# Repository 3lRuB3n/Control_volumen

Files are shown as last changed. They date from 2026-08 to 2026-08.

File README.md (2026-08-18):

# Instalación
## Requisitos
Circuitpython 
# Componentes y conexiones
A la hora de fabricar el hardware de este proyecto se han usado como base para las conexiones dos placas perforadas de 5x7cm.
## Componentes
- 1 Raspberry pi pico (Puede que funcione con una Raspberry pi pico 2)
- Módulo ESP01/ESP01s
- Pantalla oled 1.3in con controlado SH1106
- 5 Pulsadores del tipo (?) de 6x6x11.5 mm
- 1 Codificador rotativo del tipo EC11
- 1 Resistencia Pull-Up para el ESP01
## Conexiones
1. GP20, GP21: A, B codificador
2. GP6: Pulsador **Silenciar**
3. GP13: Pulsador **Siguiente** pista
4. GP15: Pulsador pista **Anterior**
5. GP14: Pulsador **Play/Pausa**
6. GP5: Pulsador **Cambio Dispositivo**
7. GP28: Pulsador **On/Off**

# Estructuras de los programas
## Estructura del programa de la Raspberry Pi
1. Code.py; Donde ocurre el bucle principal.
2. ControlDisplay.py; Encargado del control del SH1106.
3. Cadena2Imagen.py; Convierte un txt a bitmap de displayio
4. even.py; Encargado de declarar los inputs del dispositivo
5. recep.py; Alberga la clase **recep** y los métodos de envío a los dispositivos conectados por USB
6. wled.py; #TODO, capa de traducción de las funciones de esp.py para que las reconozca un dispositivo WLED
7. esp.py; Encargado de la comunicación con el módulo ESP01/01s, encargado de enviar comandos mediante ESPNow a otros receptores.
## Estructura del programa del ESP maestro
#TODO
## Estructura del programa del ESP esclavo
#TODO

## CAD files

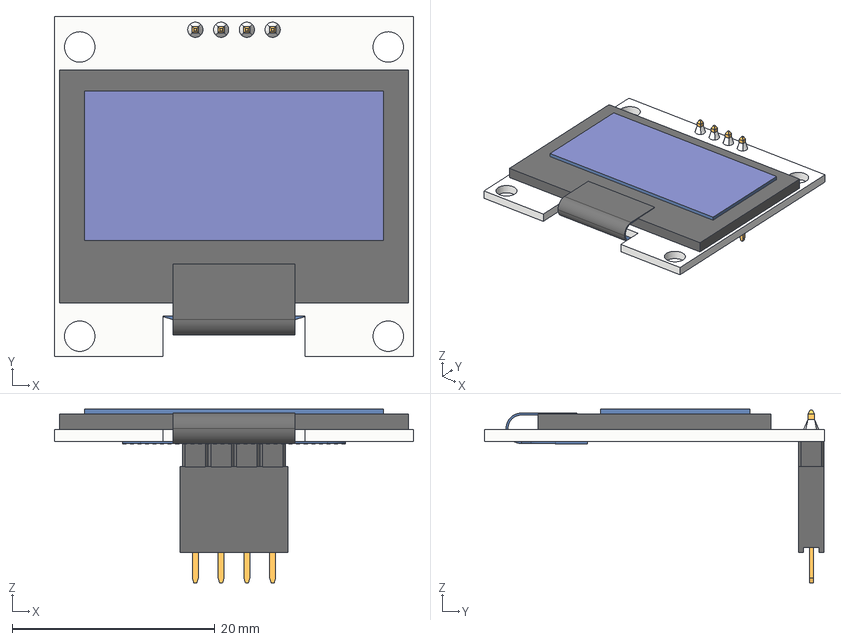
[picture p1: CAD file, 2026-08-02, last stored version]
CAD/128x64-1-3-inch-oled-graphic-display-4-pin-is-i2c-1.snapshot.3/PCB v8.step
35.4 x 33.5 x 17.1 mm
Board
PIN HEADER MALE 2.54MM P4
LCD
FLEX FILM
4 lü Lehim
PIN HEADER FAMALE 2.54MM P4

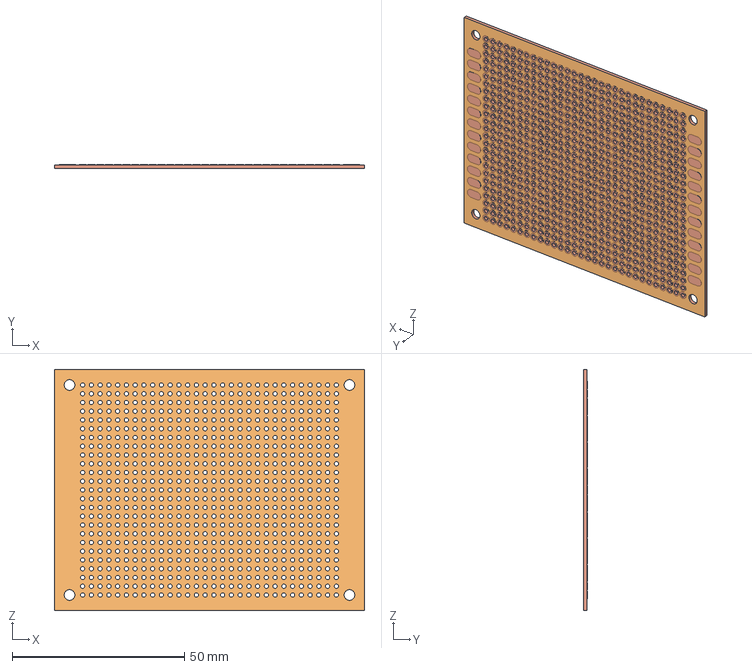
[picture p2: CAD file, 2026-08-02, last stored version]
CAD/adafruit-perfboard-1.snapshot.2/Adafruit_ProtoBoard.stp
90.0 x 1.05 x 70.0 mm

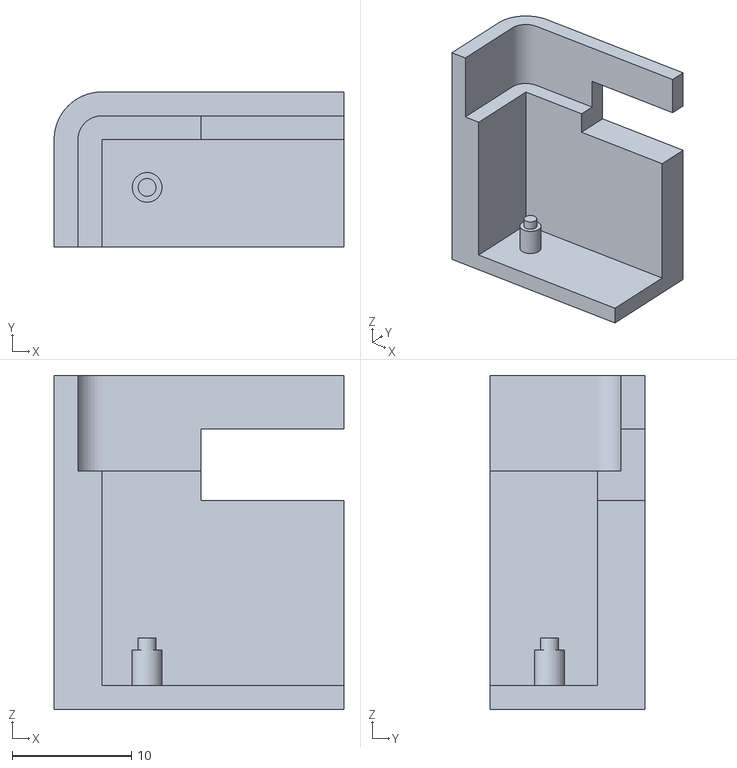
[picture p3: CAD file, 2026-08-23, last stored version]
CAD/Test base.stl
24.3 x 13.0 x 28.0

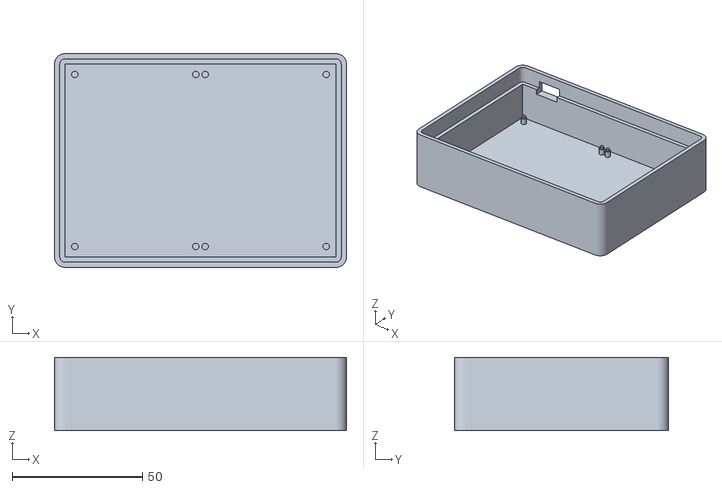
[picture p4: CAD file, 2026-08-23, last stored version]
CAD/Base.stl
112.0 x 82.0 x 28.0

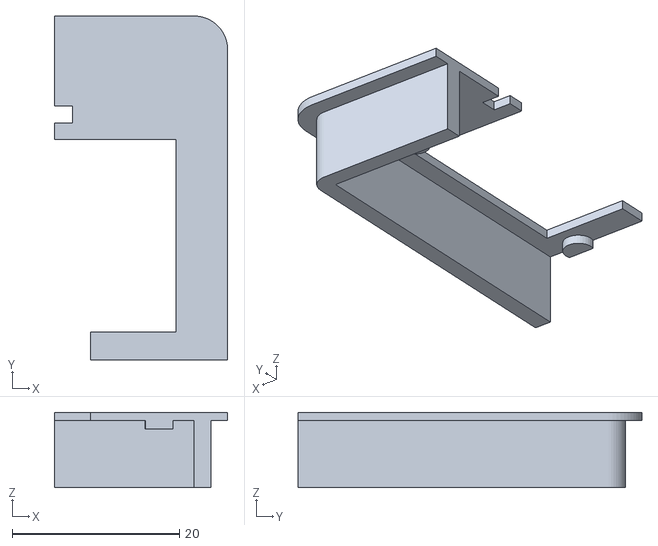
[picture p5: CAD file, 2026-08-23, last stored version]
CAD/Test Tapa.stl
20.7 x 41.1 x 9.00

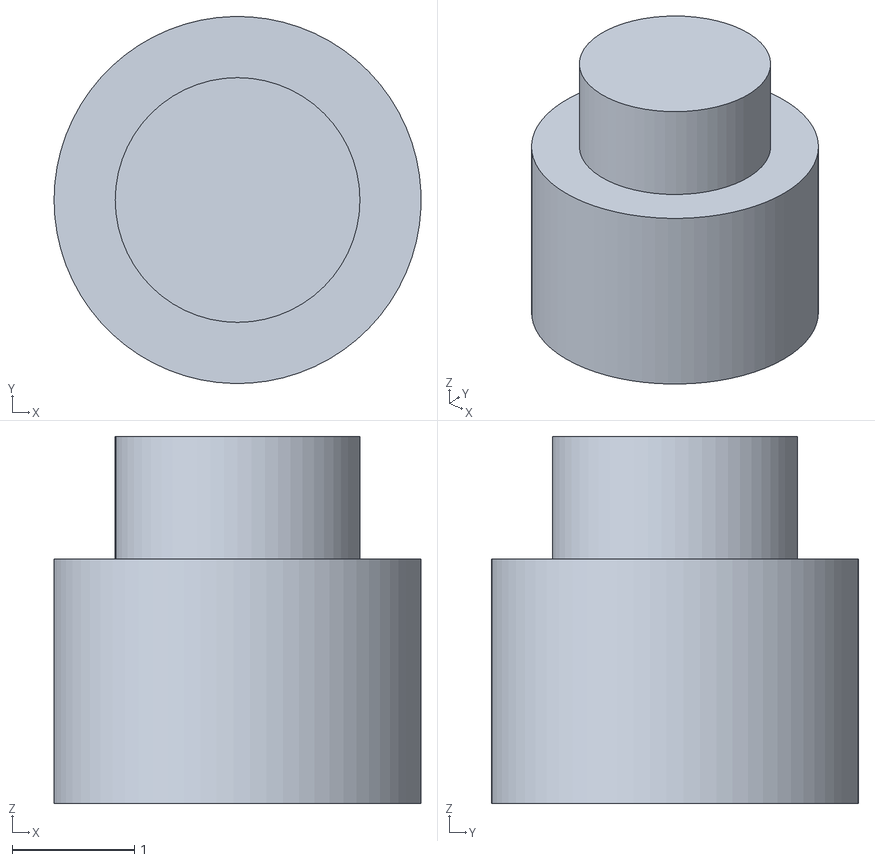
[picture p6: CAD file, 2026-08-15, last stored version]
CAD/Cono prueba.stl
3.00 x 3.00 x 3.00

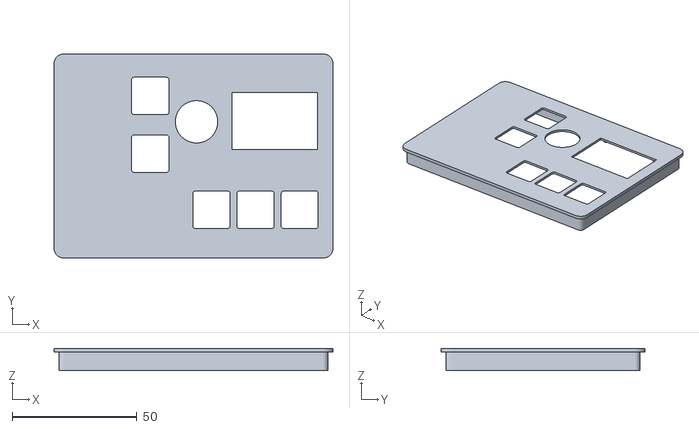
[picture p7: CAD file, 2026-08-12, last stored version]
CAD/Tapa.stl
112.0 x 82.0 x 9.00

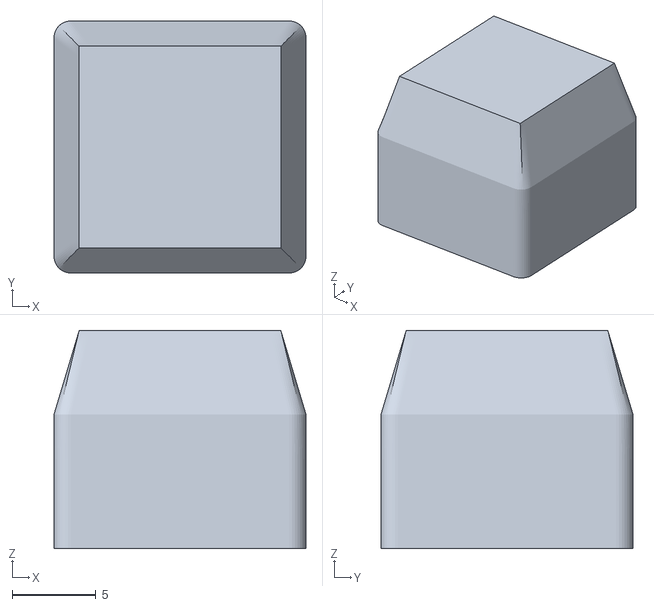
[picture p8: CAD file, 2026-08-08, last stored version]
CAD/Tecla.stl
15.0 x 15.0 x 13.0

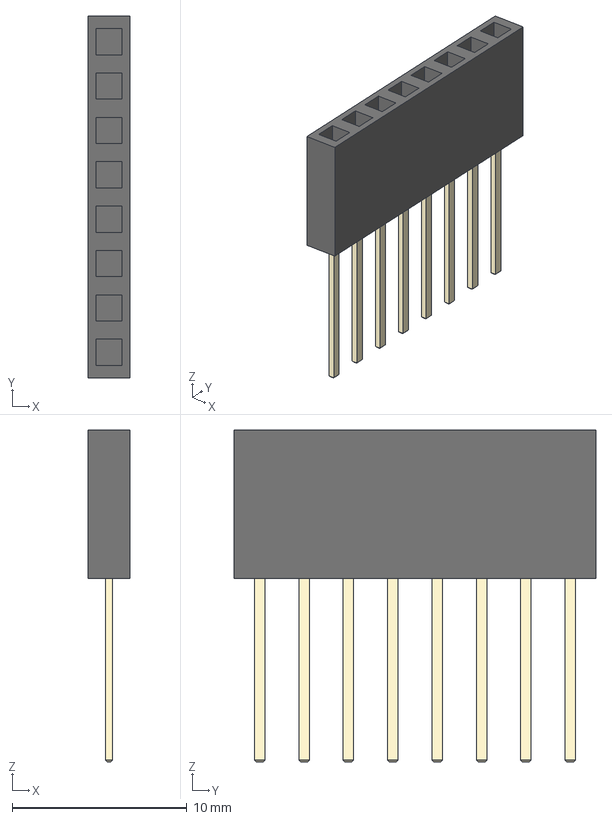
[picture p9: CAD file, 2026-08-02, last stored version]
CAD/Conectores pines hembra macho.step
2.40 x 20.7 x 19.0 mm

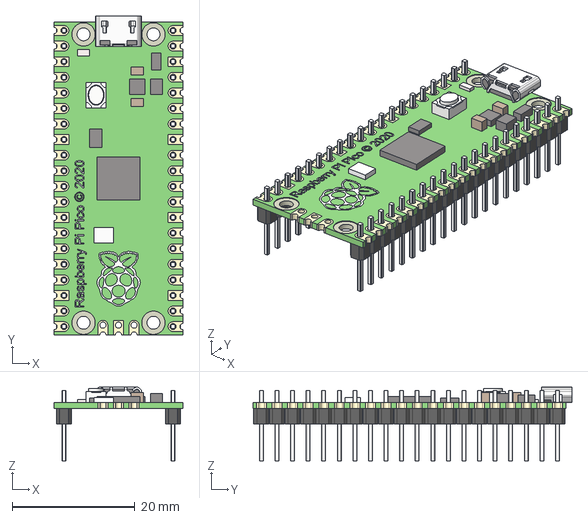
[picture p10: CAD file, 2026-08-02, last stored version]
CAD/pi pico.step
21.0 x 52.0 x 12.0 mm
ножка x 20
ножка v3(Mirror) x 20

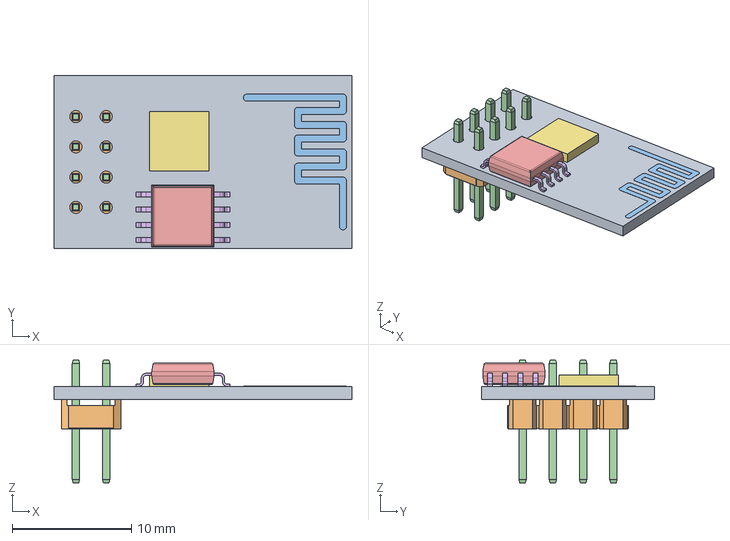
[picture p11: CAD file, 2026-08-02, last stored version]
CAD/ESP01.stp
25.0 x 14.5 x 10.3 mm

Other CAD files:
CAD/128x64-1-3-inch-oled-graphic-display-4-pin-is-i2c-1.snapshot.3/PCB v8.f3d
CAD/Carcasa y botones.f3d
CAD/Carcasa.f3d
CAD/Placa.f3d
CAD/adafruit-perfboard-1.snapshot.2/Adafruit_ProtoBoard.ipt

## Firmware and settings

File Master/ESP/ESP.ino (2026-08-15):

#include <ESP8266WiFi.h>
#include <espnow.h>

#define debug Serial.println      //habría que cambiar los println por print, o recortar los mensajes que mande en el receptor (La raspberrry pi pico, con circuitpython)

unsigned char dir[20*6]; //20 direcciones máximas (cosas de esp_now) y 6 bytes (ordenados así por cosas de las ip)
char mensaje[32];
bool estado = false;

void setup(){
  Serial.begin(74880);
  WiFi.mode(WIFI_STA);
  if (esp_now_init() != 0) return; 
  delay(1500);
  Serial.print("ok");

  esp_now_set_self_role(ESP_NOW_ROLE_CONTROLLER);
  esp_now_register_send_cb(onDataSent);
  //debug("addPeers");
  addPeers();
}

void loop(){
  debug("loop");
  String data = leer();
  unsigned char obj = letraA20(data[0]);
  String mens_temp = data.substring(1);
  mens_temp.toCharArray(mensaje, 32); //pasarlo como string lo jode por alguna razon
  
  for(int i=0;i<6;i++){
    debug((dir+obj*6)[i],HEX);
  }
  do{
  esp_now_send(dir+obj*6, (uint8_t *) &mensaje, sizeof(mensaje)); //mete esto en un do while, puede que lo de la dirección no le haga gracia a la funcion esta
  }while(estado);
}

void addPeers(){
  int N_rec = letraA20(leer()[0]); //a=0, b=1, c=2 ... u=20
  debug(N_rec); ///
  if(N_rec == 0){
    debug("a mimir");
    ESP.deepSleep(0); //Se pone en stand-by hasta que se reinicie
  }
  for(int j = 0;j<N_rec;j++){
    delay(400);
    debug("for");
    String dir_char = leer(); //lee la siguiente dirección
    //debug(dir_char); ///
    for(int i=0;i<11;i+=2){
      dir[j*6+i/2] = char2hex(dir_char[i])*16 + char2hex(dir_char[i+1]);
      //esp_now_add_peer(direccion , ESP_NOW_ROLE_SLAVE, 1, NULL, 0);
      debug(dir[j*6+i/2], HEX);
    }
  }
  Serial.println("okk");
}

String leer(){ //leer el puerto serie comprimido a una sola funcion. Puede que sobre el delay o que sea excesivo (seguramente)
  while(!Serial.available()){
    delay(100);
  }
  String dato = Serial.readString();
  dato.trim();
  debug(dato);
  return dato;
}

byte char2hex(char letra){
  if(letra >= '0' && letra <= '9') 
    return letra - '0';
  else if(letra >= 'A' && letra <= 'F')
    return letra - 'A' + 10;
  else return 0;
}

byte letraA20(char letra){
  //println(letra - 'a');
  return letra - 'a';
}

void onDataSent(byte *mac_addr, byte sendStatus){
  if(sendStatus){
    debug("Malo");
  }else{
    debug("Bueno");
  }
  estado = sendStatus;
}

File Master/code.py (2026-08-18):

import esp, even, recep as rec, ControlDisplay as CD
from time import sleep as sl
from time import monotonic as t_act

disp = 0
ind = 0

t_espera = 30 #seg
t_even = t_act()
on = True #para saber si el sistema debe estar activo

#aqui van los receptores con la direccion fisica y la mac
disp = rec.recep("test", "0",0, 'u'), rec.recep("USB","0",1,'u')#, rec.recep("ESPNow","40915151EDA2",3,'a')
Ndisp = len(disp)
CD.g_rec[0] = disp[ind].img
#esp.setup(disp) #envía las direcciones MAC de los receptores al ESP

while True:
    if t_act() > t_even + t_espera:
        on = False
    
    CD.marco.hidden = not on
    pend, comandos = even.actu(even.pines)
    rotacion = even.act_inc(even.encoder)
    CD.apaga() #Oculta los grupos de los inputs tras un periodo corto de inactividad
    
    if pend and on: #Todo lo que tenga que ver con botones
        t_event = t_act()
        for i in comandos:
            if i == "sil":
                CD.g_altavoz[0] = 2
            CD.ilumina(i)
            if i == "disp":
                ind = (ind+1)%Ndisp
                CD.g_rec[0] = disp[ind].img #cambia la imagen del receptor a la del dispositivo de turno
            else:
                disp[ind].envia(i)
    if rotacion != 0 and on: #Únicamente el encoder
        t_event = t_act()
        CD.g_altavoz[0] = 0 if rotacion>0 else 1
        CD.ilumina("altavoz")
        rec.envia_audio(rotacion, disp[ind])
        CD.g_altavoz.hidden = False
        
    if (rotacion != 0 or pend) and not on:
        on = True
        t_even = t_act()
    sl(0.01)

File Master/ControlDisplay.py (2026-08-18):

import displayio as dio
import adafruit_displayio_sh1106, board, busio, os
import Cadena2Imagen as im
from time import monotonic as t_act

dio.release_displays()

#El ancho tiene que ser 130, si no habrá leak de memoria en la pantalla
ancho, alto = 130, 64												##SCL, SDA
display = adafruit_displayio_sh1106.SH1106(dio.I2CDisplay(busio.I2C(board.GP19, board.GP18), device_address=0x3C), width=ancho, height=alto)

#Paleta
paleta = dio.Palette(2)
paleta[0] = 0
paleta[1] = 0xFFFFFF

#Crea el grupo base
marco = dio.Group()
display.root_group = marco
marco.x = 2
marco.y = 0

os.chdir("/imagenes")

#Convierte las imagenes almacenadas en txt a un bitmap de displayio
receptores = im.btm("receptores.txt")
onOff = im.btm("onOff.txt")
playPau = im.btm("playPau.txt")
prev = im.btm("prev.txt")
sig = im.btm("sig.txt")
altavoz = im.btm("altavoz.txt")
camb = im.btm("camb.txt")

#Crea los grupos con sus respectivos sprites / spritesheets
g_rec = dio.TileGrid(receptores.mapa, pixel_shader=paleta, width=1, height=1, tile_width=32, tile_height=46)
g_onOff = dio.TileGrid(onOff.mapa, pixel_shader=paleta)
g_playPau = dio.TileGrid(playPau.mapa, pixel_shader=paleta)
g_prev = dio.TileGrid(prev.mapa, pixel_shader=paleta)
g_sig = dio.TileGrid(sig.mapa, pixel_shader=paleta)
g_disp = dio.TileGrid(camb.mapa, pixel_shader=paleta)
g_altavoz = dio.TileGrid(altavoz.mapa, pixel_shader=paleta, width=1, height=1, tile_width=19, tile_height=17)

#Añade los grupos al marco principal
marco.append(g_rec)
marco.append(g_onOff)
marco.append(g_playPau)
marco.append(g_prev)
marco.append(g_sig)
marco.append(g_altavoz)
marco.append(g_disp)
    
#Extraidos del .aseprite, añadiendo 2 a la coordenada y de cada grupo por problemas de dimensionamiento del display
g_rec.x, g_rec.y = 1, 9
g_onOff.x, g_onOff.y = 98, 11
g_playPau.x, g_playPau.y = 72, 40
g_prev.x, g_prev.y = 49, 40
g_sig.x, g_sig.y, = 98, 40
g_altavoz.x, g_altavoz.y, = 73, 12
g_disp.x, g_disp.y, = 49, 12

t_encen = 0
def apaga():	#Que se apague x tiempo usando una variable global y monotonic
    global t_encen
    if t_act() > t_encen + 1:
        g_onOff.hidden = True
        g_playPau.hidden = True
        g_prev.hidden = True
        g_sig.hidden = True
        g_altavoz.hidden = True
        g_disp.hidden = True
    
def ilumina(mensaje): #Activa el grupo de turno
    global t_encen
    t_encen = t_act()
    #print(mensaje)
    dicc = {"ant":g_prev,
            "sig":g_sig,
            "playPau":g_playPau,
            "disp":g_disp,
            "altavoz":g_altavoz,
            "onOff": g_onOff,
            "sil": g_altavoz
            }
    dicc.get(mensaje).hidden = False

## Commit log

2026-08-02 Primer commit
    [Adafruit_ProtoBoard.ipt, Adafruit_ProtoBoard.stp, Conectores pines hembra macho.step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]
2026-08-02 Update ESP.ino
    Sería más simple programar todo pensando en comandos AT, pero haría falta un ESP32 en vez de un 8266
2026-08-02 Update ESP.ino
    Actualizado el método para indicar el numero de receptores.
    Necesario arreglo de la línea 27, posiblemente necesario rehacer como se manejan las direcciones
    [ESP.ino]
2026-08-03 Update ESP.ino
    Aparentemente funcional, a la espera de tener un receptor y programar la parte de la raspberry pi pico
2026-08-03 Create Plantilla.txt
    Plantilla por la que programar los receptores varios (hdmi-cec, equipo de sonido...). ESPNow hay que manejarlo a parte completamente
2026-08-03 Creación ESP.py
    hay discrepancias entre los mensajes que se envían y reciben por el puerto serie. Seguramente se cambiará el .ino
2026-08-03 Cambio imagenes receptores
    Ahora hay que especificar que sprite corresponde a que receptor, por lo que ahora se pueden repetir y desordenar en la spritesheet.
2026-08-03 Update Ordenador.aseprite
    Añadido Sprite de WLED-Tele
2026-08-04 Pequeños arreglos y paridad comunicacion
    Cada objeto receptor de CirPy tiene una letra asociada del 0 al 19 (a-t)
    [ESP.ino, code.py, esp.py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]
2026-08-04 Declarado ESPNow de prueba
2026-08-04 Nuevo sprte de cambio de receptor
    Convertido a mano, puede que haya que cambiarlo
2026-08-07 Primera versión carcasa y teclas
    Todo son medidas teóricas, la tapa no tiene los agujeros en los lugares correspondientes, necesito aclarar antes la disposición de todos los componentes
    [Adafruit_ProtoBoard.ipt, Adafruit_ProtoBoard.stp, Base.stl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]
2026-08-08 Act modelos
    [Carcasa.f3d, Tecla.stl]
2026-08-12 Create Carcasa y botones.f3d
    [Carcasa y botones.f3d]
2026-08-15 Integración con hardware 1/?
    Se ha desactivado la comunicación con el ESP01, no se ha probado
2026-08-15 Test diámetros
    Para ver el diámetro mínimo que puede hacer la impresora para comprobar si puede hacer los enganches de la placa en la carcasa
    [Cono prueba.stl]
2026-08-15 Create Test base.stl
    Test general para la base de la carcasa, es la carcasa recortada
    [Test base.stl]
2026-08-17 Fin integración con el hardware
    Ya están todas las conexiones hechas y funcionales, incluidas las del esp01.
2026-08-17 Update code.py
    Ahora la pantalla se apaga a los 30s de inactividad. La primera interacción que se tenga con el dispositivo servirá para despertarlo. Puede que sea mejor quitar eso pero de momento se queda
2026-08-18 Actualización modelos
    [Base.stl, Carcasa y botones.f3d, Cono prueba.stl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]
2026-09-17 Limpieza Archivos
    [Base.stl, Carcasa y botones.f3d, Tecla.stl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]
